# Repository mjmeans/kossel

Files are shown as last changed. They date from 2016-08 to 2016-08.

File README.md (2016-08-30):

Release status
==============

This is for my modified Kossel Mini using 15mm OpenBeam extrusions 360x750.

Credits
=======

* Based on Johann Rocholl's https://github.com/jcrocholl/kossel.
* recirculating.scad, recirculating.stl from https://github.com/jcrocholl/recirculating.
* framebrace_v2.stl from http://www.thingiverse.com/thing:626279.
* riser.scad, riser.stl from http://www.thingiverse.com/thing:705780.
* new_plate.stl, new_endstop.stl from http://www.thingiverse.com/thing:781634.
* TopMntBracket.stl from http://www.thingiverse.com/thing:843485.
* clip.scad, clip.stl from http://www.thingiverse.com/thing:783810
* molex_clips.stl, pscover_v2.scad, pscover_v2_with_aux_struts.stl from http://www.thingiverse.com/thing:235754.
* 3DR_LCD_Bracket_rev1.STL, 3DR_LCD_Pivot_rev1.STL from http://www.thingiverse.com/thing:467289.
* bracket_long.stl from http://www.thingiverse.com/thing:996476.
* ob-tube-jig_x6.stl from http://www.thingiverse.com/thing:291455.
* plate.stl, Bearing-flanged.stl from http://www.thingiverse.com/thing:454808.
* 3D_PlastX_reel_adapter.stl from http://www.thingiverse.com/thing:1666487.
* Kossel_Endstop_Mount.stl from http://www.thingiverse.com/thing:1305559.
* Kossel_Cable_Tidy.stl from http://www.thingiverse.com/thing:523867.
* mk_arm_clamp_short.stl from http://www.thingiverse.com/thing:330482.
* Dasaki_ramps_enclosure_base_kossel.stl from http://www.thingiverse.com/thing:1308919.
* dasaki_ramps_enclosure_cover_v2.stl from http://www.thingiverse.com/thing:761806.
* B-struder_1515_90_plate.stl from http://www.thingiverse.com/thing:1132070.
* B-struder_arm_M5.stl from http://www.thingiverse.com/thing:711401.
* 3DR_Pablo_LCD_distance_cylinder.stl, 3DR_Pablo_LCD_button_kill_improved.stl, 3DR_Pablo_LCD_case_bottom.stl, 3DR_Pablo_LCD_case_top.stl from http://www.thingiverse.com/thing:213852.
* zprobe_clamp.stl from http://www.thingiverse.com/thing:117981.
* Filament_Guide.stl from https://www.thingiverse.com/thing:1327363.

Things I modified
=================

* kossel-plus-fsr-holders-modified\* based on https://www.youmagine.com/designs/kossel-plus-fsr-holders. Modified by me to include a nut pocket.
* Kossel_Mini_Custom_Z_Probe_Retractable_-_3mm_probe_modified\ basd on http://www.thingiverse.com/thing:317205. Modified by me as follows: use an actual 3mm brass rod instead of 1/8"; lower it so that the arm bend in the rod sits at the effector level to allow for a longer arm; center the holder so that the rod sits direclty between the effector screws; strengthen the foot and add another small foot to go underneath the effector.

Things I made
=============

* spool_adapter_shim.* so that the longer arm designed to fit a 20mm extrusion will fit snug on 15mm extrusions.
* lcd_mount_bushing.* so that the 3DR_LCD_Bracket_rev1.STL designed for larger bolt will work with M3 bolt.
* kossel_retractable_helper.* so that the retractable z probe can be stowed directly at the back of the printer with a cool look like the frame braces.

Links
=====

* Bill of Materials: http://reprap.org/wiki/Kossel
* Mailing list: http://groups.google.com/group/deltabot
* Project history: http://deltabot.tumblr.com

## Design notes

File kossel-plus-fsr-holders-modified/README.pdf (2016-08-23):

# Kossel Plus FSR Holders

## By: (Haydn Huntley)

License: Commercial use is not allowed, you must attribute the creator, you may remix this work and the remixed work should be made available under

this license.

## Published on: Apr 01, 2016 Located at: http://www.youmagine.com/designs/kossel-plus-fsr-holders Short description:

These hold 3 FSR's, which the glass bed rests on, so that you can use the tip of the hotend as the probe. This system works extremely well! Description: <p>This FSR holder works quite well.</p><p>It is easy to modify it for different diameter or

thickness glass beds.</p><p>You can place small (approximately 1mm thick 5mm x 5mm) squares of foam between the glass and the key piece which swivels to lock the glass in place. &nbsp;This pre-loads the FSR so that you can better control how sensitive it is.</p><p>I used a drop of rubber cement to attach the round plastic buttons to the bottom of the glass. &nbsp;This keeps the glass

from being able to rotate.</p><p>The glass should lightly rest against the heads of the socket head cap screws so that it can easily move up and down. &nbsp;Tap on the glass to verify that the microcontroller triggers easily&nbsp;--&nbsp;a&nbsp;red&nbsp;LED&nbsp;will light&nbsp;when

it&nbsp;triggers.</p><p>The sensitive area is a triangle with the three FSR's at its corners.</p><p>I use Wing&nbsp;Wong &amp;&nbsp;Ian&nbsp;Lee's&nbsp;code for the Adafruit Trinket, but you could use this with John SL's board. &nbsp;With a Trinket, wire all three FSR's in parallel, so that pressing on any one will trigger it. &nbsp;Note:

the&nbsp;Trinket&nbsp;code&nbsp;is not&nbsp;limited&nbsp;by&nbsp;any&nbsp;license.</p><p>Someone&nbsp;else&nbsp;also&nbsp;made&nbsp;the&nbsp;Trinket&nbsp;wiring&nbsp;diagram.&nbsp;Note:&nbsp;I&nbsp;found&nbsp;I&nbsp;had&nbsp;to&nbsp;wire&nbsp;5v

from&nbsp;the&nbsp;RAMPS&nbsp;to&nbsp;USB+&nbsp;on the&nbsp;Trinket. &nbsp;The&nbsp;BAT+&nbsp;input&nbsp;is&nbsp;for&nbsp;more&nbsp;than&nbsp;5v&nbsp;(for&nbsp;example&nbsp;from

a&nbsp;battery),&nbsp;and&nbsp;the&nbsp;voltage&nbsp;regulator&nbsp;it
is&nbsp;attached&nbsp;to&nbsp;seems&nbsp;to&nbsp;require&nbsp;a&nbsp;little&nbsp;more&nbsp;than&nbsp;5v&nbsp;to deliver&nbsp;5v&nbsp;to&nbsp;operate&nbsp;the&nbsp;Trinket.<br></p><p>I have been building Kossel Plus printers (my own design) using these. &nbsp;They allow the effector to be

simpler, because it doesn't have to include a z-probe. &nbsp;I use RC's Marlin for auto calibration. &nbsp;Here is a link to&nbsp;my&nbsp;calibration&nbsp;instructions: &nbsp;<a rel="nofollow"

target="_blank" href="http://www.maui- 3d.com/kcZeroBacklashInstallation.php#calibration">http://www.maui- 3d.com/kcZeroBacklashInstallation.php#calibration</a></p>

If you can, please use the online documentation found at http://www.youmagine.com/designs/kossel- plus-fsr-holders because those may have been been updated. Also, there you can interact and

provide praise and/or feedback.

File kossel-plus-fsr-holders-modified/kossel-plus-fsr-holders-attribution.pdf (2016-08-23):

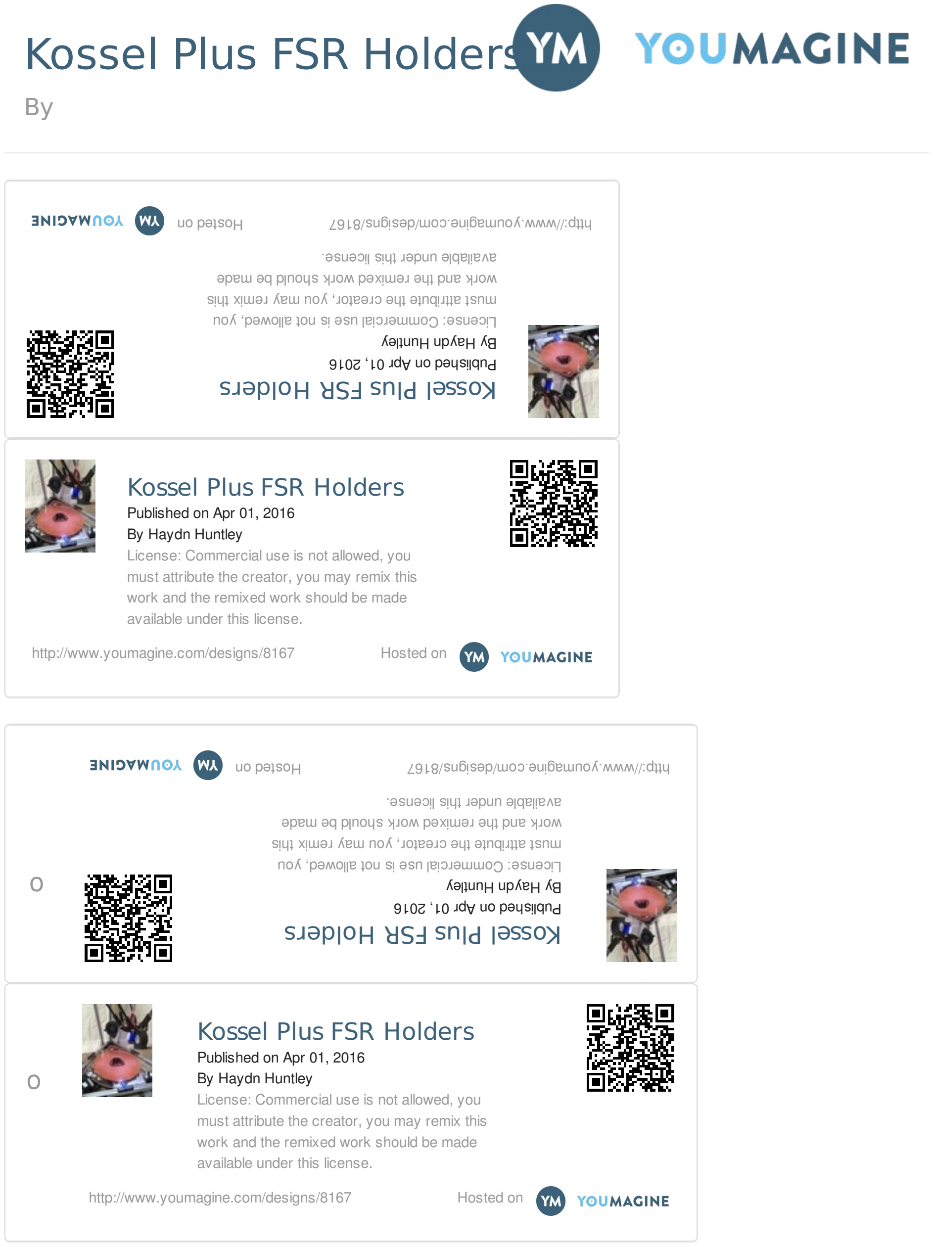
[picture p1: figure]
Kossel Plus FSR Holders; Published on Apr 01, 2016 By Haydn Huntley; available under this license.; http://www.youmagine.com/designs/8167; Hosted on

License: Commercial use is not allowed, you must attribute the creator, you may remix this work and the remixed work should be made

License: Commercial use is not allowed, you must attribute the creator, you may remix this work and the remixed work should be made

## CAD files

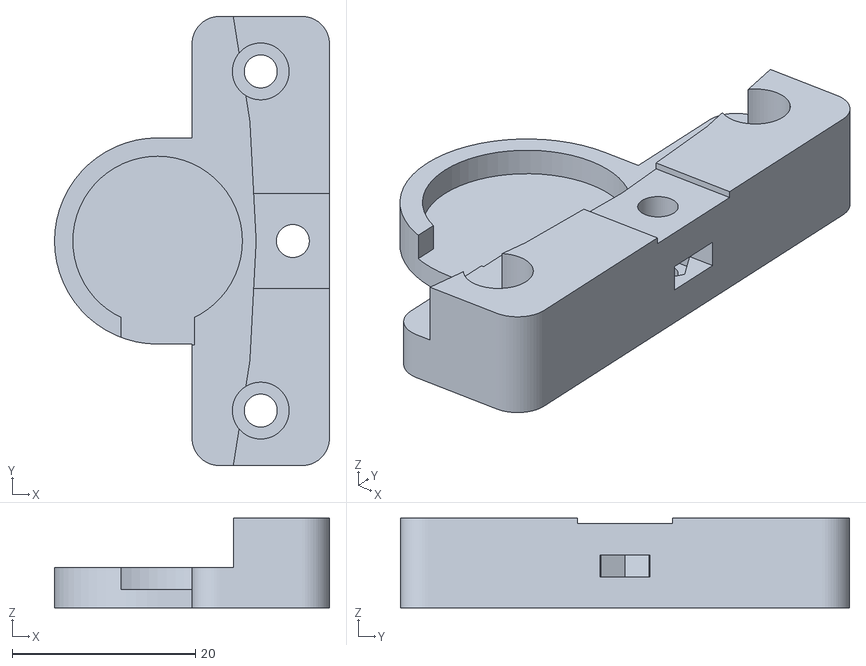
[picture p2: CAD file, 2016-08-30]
kossel-plus-fsr-holders-modified/fsrHolder.stl
30.0 x 49.0 x 9.80

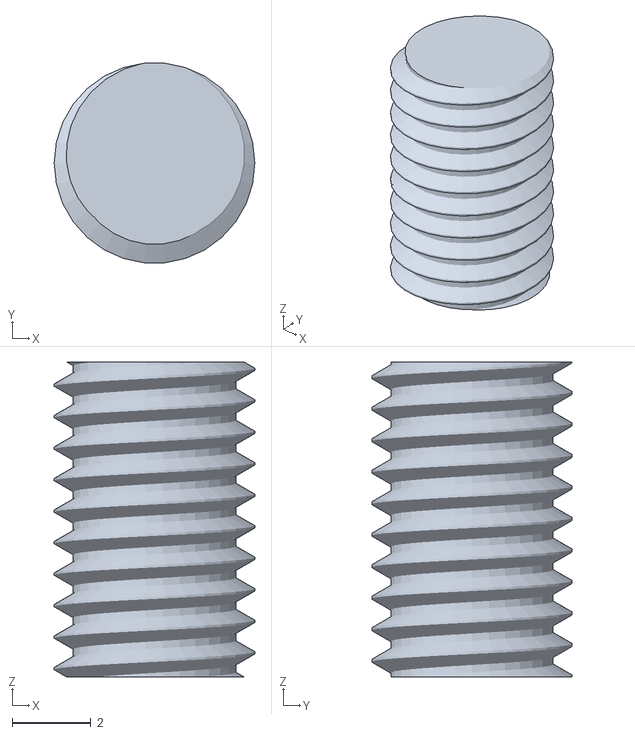
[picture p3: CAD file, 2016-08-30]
Kossel_Mini_Custom_Z_Probe_Retractable_-_3mm_probe_modified/m5_internal.stl
5.10 x 5.07 x 8.00

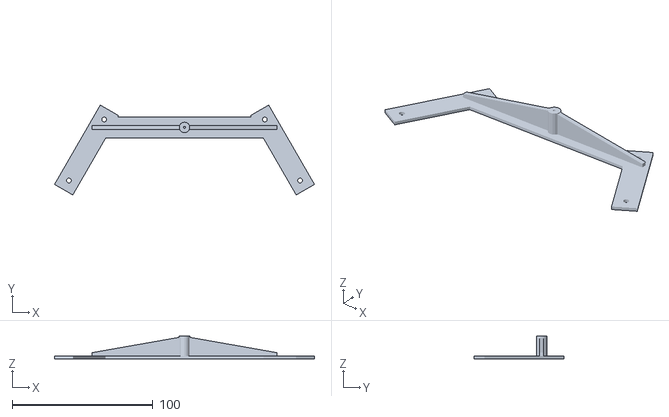
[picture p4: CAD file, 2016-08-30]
kossel_retractable_helper.stl
184.5 x 63.8 x 16.0

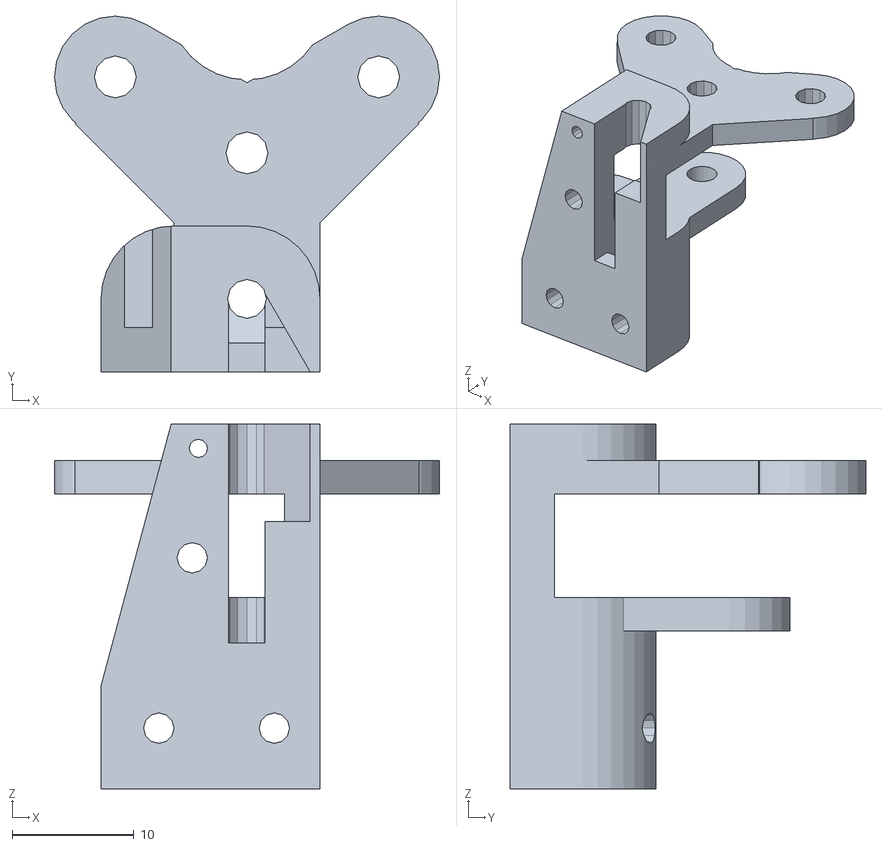
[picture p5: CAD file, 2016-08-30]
Kossel_Mini_Custom_Z_Probe_Retractable_-_3mm_probe_modified/retractable-custom.stl
31.7 x 29.2 x 30.0

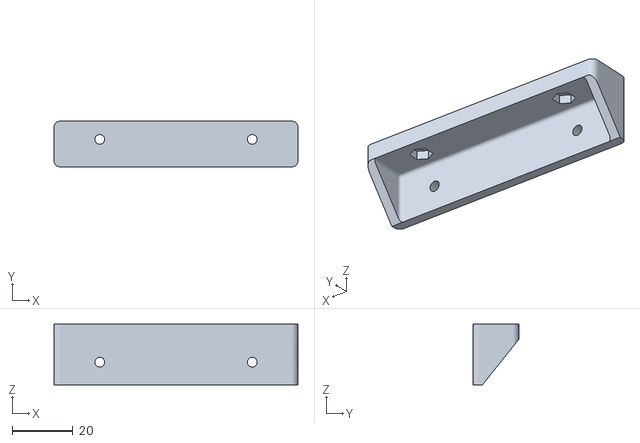
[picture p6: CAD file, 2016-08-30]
TopMntBracket.stl
80.0 x 15.0 x 20.0

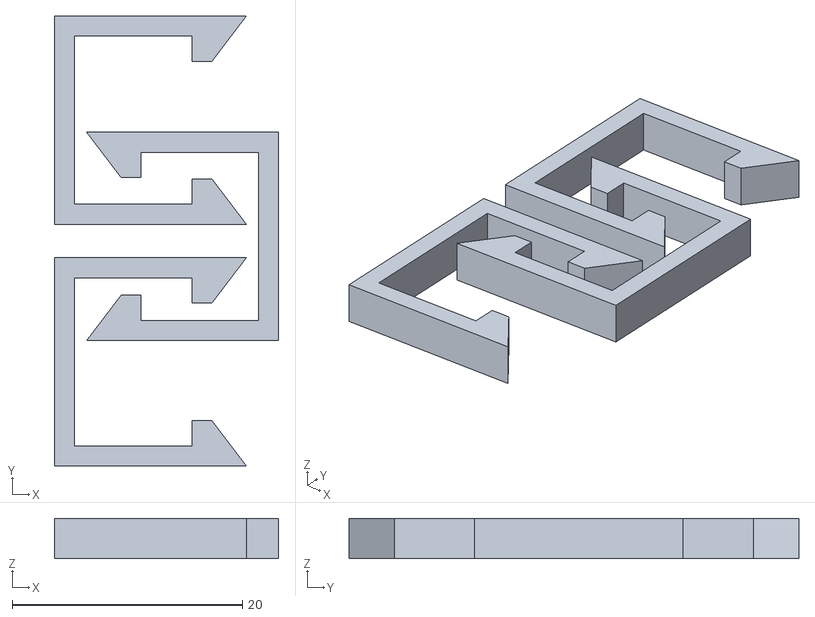
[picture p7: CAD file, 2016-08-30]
molex_clips.stl
19.5 x 39.1 x 3.50

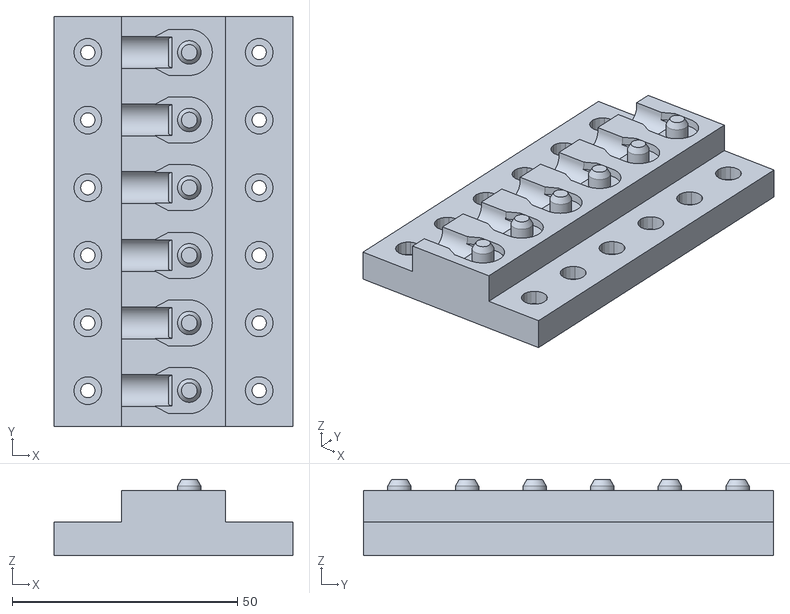
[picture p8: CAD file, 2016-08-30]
ob-tube-jig_x6.stl
53.0 x 91.0 x 16.9

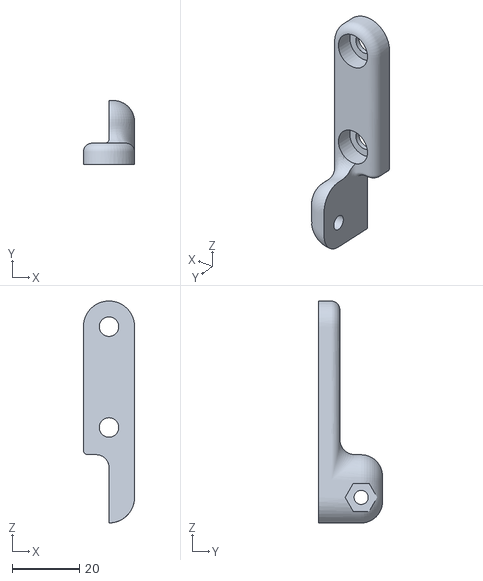
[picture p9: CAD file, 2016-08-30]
3DR_LCD_Bracket_rev1.STL
15.2 x 19.1 x 66.0

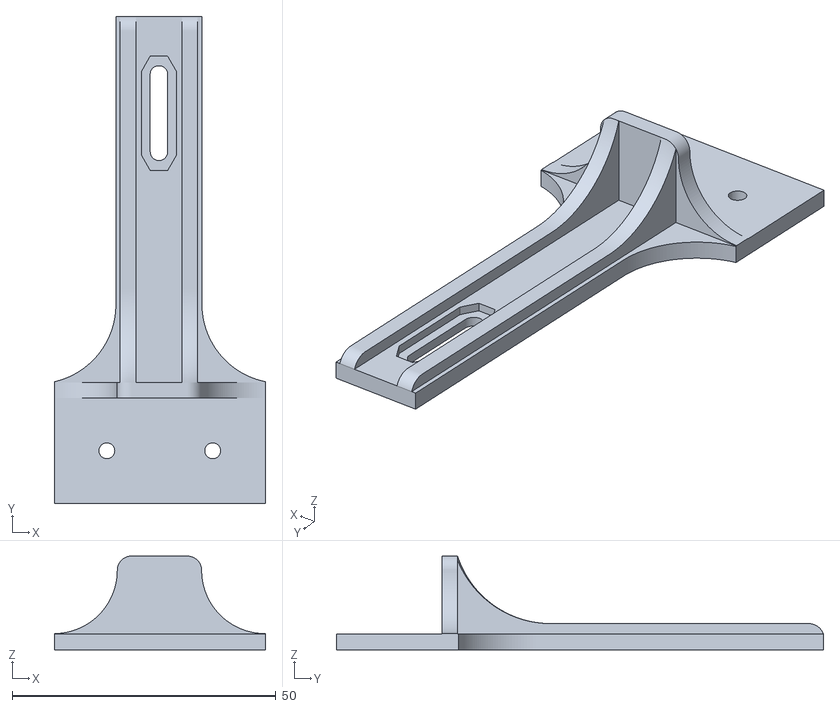
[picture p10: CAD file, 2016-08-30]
bracket_long.stl
40.0 x 92.3 x 17.8

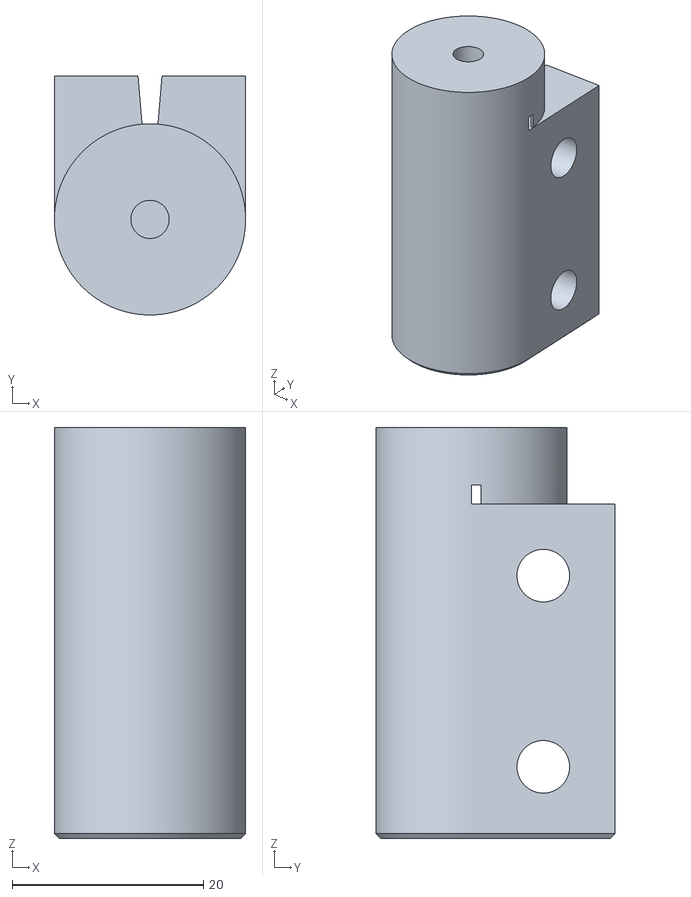
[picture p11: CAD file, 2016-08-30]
mk_arm_clamp_short.stl
20.0 x 25.0 x 43.0

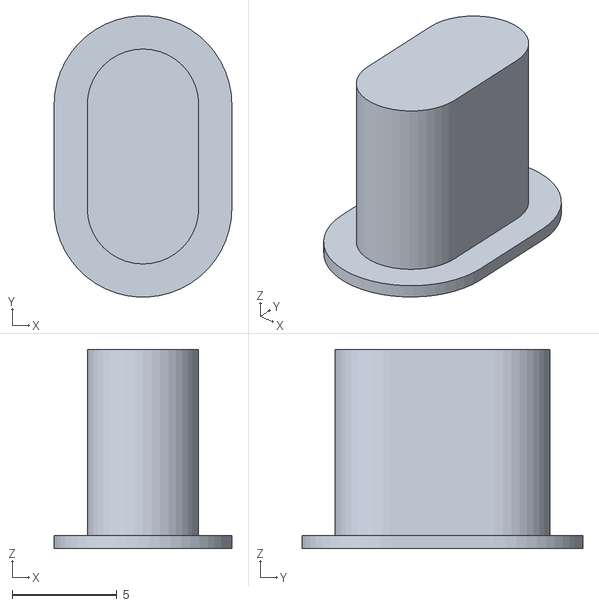
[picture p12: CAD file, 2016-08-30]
3DR_Pablo_LCD_button_kill_improved.stl
8.51 x 13.4 x 9.53

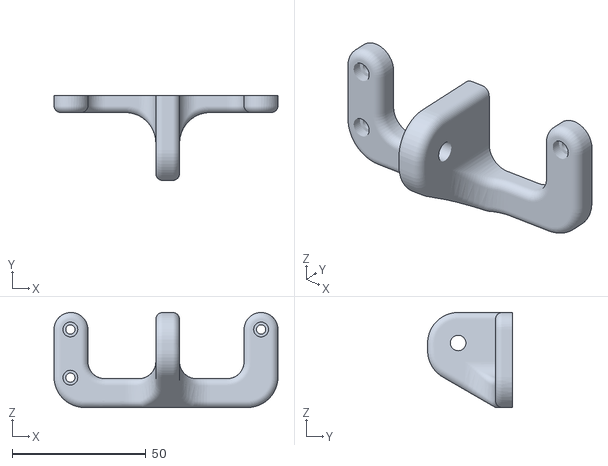
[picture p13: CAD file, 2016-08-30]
3DR_LCD_Pivot_rev1.STL
83.8 x 31.8 x 35.6

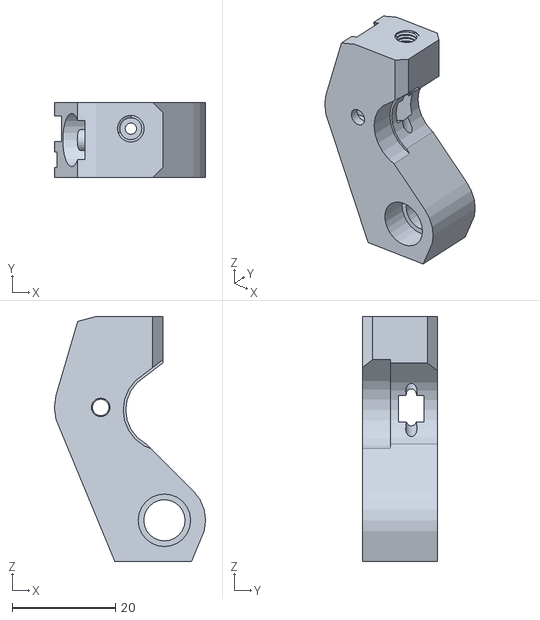
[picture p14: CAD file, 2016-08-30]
B-struder_arm_M5.stl
29.4 x 14.6 x 47.6

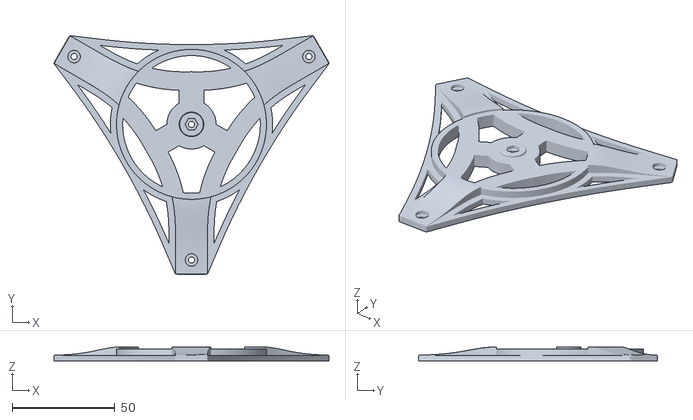
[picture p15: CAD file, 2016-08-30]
plate.stl
133.9 x 116.2 x 7.00

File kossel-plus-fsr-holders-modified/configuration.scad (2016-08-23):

smidge              =  0.1;
mmPerInch			= 25.4;
m3Radius            = (3.0 + 0.2) / 2;
m3LooseRadius		= m3Radius + 0.2;
m3HeadHeight        = 3.0;
m3LooseHeadRadius   = (5.4 + 0.6) / 2;
m3NutRadius         = 6.01 / 2;
m3NutRadiusMin      = 5.5 / 2;
m3LooseNutRadius    = m3NutRadius + 0.2;
m3NutHeight			= 2.4;
m3LockNutRadius     = (6.25 + 0.75) / 2;
m3LockNutHeight     = 4.0;
ballJointSeparation = 48.0;
ballRadius			= (3/8 * mmPerInch)/2;
ballBaseRadius		= 10.0 / 2;
extrusionWidth		= 15.0;
glassRadius			= 125.0;
glassHeight			= 3.4;
nozzleWidth			= 0.5;

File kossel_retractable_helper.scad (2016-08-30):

//118
mount_length=50.0;    // the length of the mount sides
mount_width=15.0;     // the width of the mount sides
mount_thickness=2.0;  // the thickness of the mount sides
span_width=139;
span_y_offset=16;   // 22
riser_height=15;
riser_thickness=3;
$fn=16;

// Increase this if your slicer or printer make holes too tight.
extra_radius = 0.1;

// Major diameter of metric 3mm thread.
m3_major = 2.85;
m3_radius = m3_major/2 + extra_radius;
m3_wide_radius = m3_major/2 + extra_radius + 0.2;

difference() {
    union() {
        // mounting bars
        translate([span_width/2,0,0]) rotate([0,0,30]) bar();
        translate([-span_width/2,0,0]) rotate([0,0,-30]) bar();
        // span between bars
        translate([0,span_y_offset,0]) union() {
            translate([0,mount_width/4,0])
                cube([span_width-span_y_offset*2,mount_width/2,mount_thickness], center=true);
            translate([0,-mount_width/4,0])
                cube([span_width-span_y_offset,mount_width/2,mount_thickness], center=true);
        }
        translate([0,span_y_offset,0])
            cylinder(r=mount_width/4, h=riser_height);
        difference() {
            translate([0,span_y_offset,riser_height/2])
                cube([span_width-span_y_offset/2,riser_thickness,riser_height], center=true);
            translate([0,span_y_offset,riser_height+riser_height/2]) rotate([0,10,0]) 
                cube([span_width*2-span_y_offset,riser_thickness,riser_height], center=true);
            translate([0,span_y_offset,riser_height+riser_height/2]) rotate([0,-10,0]) 
                cube([span_width*2-span_y_offset,riser_thickness,riser_height], center=true);
        }
    }
    translate([0,span_y_offset,0])
        cylinder(r=m3_radius/2, h=riser_height);
}

module bar() {
    difference() {
        cube([mount_width,mount_length+mount_width,mount_thickness], center=true);
        translate([0,mount_length/2,0]) cylinder(r=m3_wide_radius, h=mount_thickness, center=true);
        translate([0,-mount_length/2,0]) cylinder(r=m3_wide_radius, h=mount_thickness, center=true);
    }
}

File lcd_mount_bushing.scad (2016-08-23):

difference() {
    union() {
        cylinder(r=4.50, h=5, $fn=32);
        cylinder(r=2.75, h=6.5, $fn=32);
    }
    cylinder(r=1.75, h=7, $fn=32);
    cylinder(r=3.25, h=2.75, $fn=32);
    translate([0,0,2.75])
        cylinder(r1=3.25, r2=1.75, h=0.5, $fn=32);
    //cube([10,10,10]);
}

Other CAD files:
Dasaki_ramps_enclosure_base_kossel.stl
dasaki_ramps_enclosure_cover_v2.stl
pscover_v2_with_aux_structs.stl
3DR_Pablo_LCD_distance_cylinder.stl
spool_adapter_shim.scad
3DR_Pablo_LCD_case_bottom.stl
3DR_Pablo_LCD_case_top.stl
3D_PlastX_reel_adapter.stl
B-struder_1515_90_plate.stl
Bearing-flanged.stl
Filament_Guide.stl
Kossel_Cable_Tidy.stl
Kossel_Endstop_Mount.stl
Kossel_Mini_Custom_Z_Probe_Retractable_-_3mm_probe_modified/configuration.scad
Kossel_Mini_Custom_Z_Probe_Retractable_-_3mm_probe_modified/effector.scad
Kossel_Mini_Custom_Z_Probe_Retractable_-_3mm_probe_modified/hotend_fan.scad
Kossel_Mini_Custom_Z_Probe_Retractable_-_3mm_probe_modified/m5_internal.scad
Kossel_Mini_Custom_Z_Probe_Retractable_-_3mm_probe_modified/microswitch.scad
Kossel_Mini_Custom_Z_Probe_Retractable_-_3mm_probe_modified/retractable-custom.scad
clip.stl
framebrace_v2.stl
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

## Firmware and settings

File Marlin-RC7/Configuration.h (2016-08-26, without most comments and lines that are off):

#define CONFIGURATION_H
#define CONFIGURATION_H_VERSION 010100
#define STRING_CONFIG_H_AUTHOR "(none, default config)" // Who made the changes.
#define SHOW_BOOTSCREEN
#define STRING_SPLASH_LINE1 SHORT_BUILD_VERSION // will be shown during boot in line 1
#define STRING_SPLASH_LINE2 WEBSITE_URL         // will be shown during boot in line 2
#define SERIAL_PORT 0
#define BAUDRATE 250000
  #define MOTHERBOARD BOARD_RAMPS_14_EFB
#define CUSTOM_MACHINE_NAME "Mini Kossel 360/750"
#define EXTRUDERS 1
#define POWER_SUPPLY 1
#define TEMP_SENSOR_0 11  // UCTRONICS E3D V6 uses NTC 3950 pre-wired thermistor
#define TEMP_SENSOR_1 0
#define TEMP_SENSOR_2 0
#define TEMP_SENSOR_3 0
#define TEMP_SENSOR_BED 11
#define MAX_REDUNDANT_TEMP_SENSOR_DIFF 5
#define TEMP_RESIDENCY_TIME 10  // (seconds)
#define TEMP_HYSTERESIS 3       // (degC) range of +/- temperatures considered "close" to the target one
#define TEMP_WINDOW     1       // (degC) Window around target to start the residency timer x degC early.
#define TEMP_BED_RESIDENCY_TIME 0   // (seconds)
#define TEMP_BED_HYSTERESIS 3       // (degC) range of +/- temperatures considered "close" to the target one
#define TEMP_BED_WINDOW     1       // (degC) Window around target to start the residency timer x degC early.
#define HEATER_0_MINTEMP 5
#define HEATER_1_MINTEMP 5
#define HEATER_2_MINTEMP 5
#define HEATER_3_MINTEMP 5
#define BED_MINTEMP 5
#define HEATER_0_MAXTEMP 275
#define HEATER_1_MAXTEMP 275
#define HEATER_2_MAXTEMP 275
#define HEATER_3_MAXTEMP 275
#define BED_MAXTEMP 150
#define PIDTEMP
#define BANG_MAX 255 // limits current to nozzle while in bang-bang mode; 255=full current
#define PID_MAX BANG_MAX // limits current to nozzle while PID is active (see PID_FUNCTIONAL_RANGE below); 255=full current
  #define PID_FUNCTIONAL_RANGE 10 // If the temperature difference between the target temperature and the actual temperature
  #define PID_INTEGRAL_DRIVE_MAX PID_MAX  //limit for the integral term
  #define K1 0.95 //smoothing factor within the PID
  #define  DEFAULT_Kp 24.31
  #define  DEFAULT_Ki 1.92
  #define  DEFAULT_Kd 77.06
#define PIDTEMPBED
#define MAX_BED_POWER 255 // limits duty cycle to bed; 255=full current
  #define PID_BED_INTEGRAL_DRIVE_MAX MAX_BED_POWER //limit for the integral term
  #define  DEFAULT_bedKp 217.87
  #define  DEFAULT_bedKi 12.59
  #define  DEFAULT_bedKd 942.38
#define PREVENT_DANGEROUS_EXTRUDE
#define PREVENT_LENGTHY_EXTRUDE
#define EXTRUDE_MINTEMP 170
#define EXTRUDE_MAXLENGTH (X_MAX_LENGTH+Y_MAX_LENGTH) //prevent extrusion of very large distances.
#define THERMAL_PROTECTION_HOTENDS // Enable thermal protection for all extruders
#define THERMAL_PROTECTION_BED     // Enable thermal protection for the heated bed
#define DELTA
  #define DELTA_SEGMENTS_PER_SECOND 200
  #define DELTA_DIAGONAL_ROD 288.0 // mm (kossel_frame_calc.xls says it should be 350.5, mk_visual_calc says it should be 296.887)
  #define DELTA_SMOOTH_ROD_OFFSET 221.12505 // mm
  #define DELTA_EFFECTOR_OFFSET 20.0 // mm (kossel_frame_calc.xls says it should be 20.0)
  #define DELTA_CARRIAGE_OFFSET 27.4 // mm (kossel_frame_calc.xls says it should be 27.0)
  #define DELTA_RADIUS (DELTA_SMOOTH_ROD_OFFSET-(DELTA_EFFECTOR_OFFSET)-(DELTA_CARRIAGE_OFFSET))
  #define DELTA_PRINTABLE_RADIUS 135.0
#define USE_ZMIN_PLUG
#define USE_XMAX_PLUG
#define USE_YMAX_PLUG
#define USE_ZMAX_PLUG
#define ENDSTOPPULLUPS // Comment this out (using // at the start of the line) to disable the endstop pullup resistors
#define X_MIN_ENDSTOP_INVERTING false // set to true to invert the logic of the endstop.
#define Y_MIN_ENDSTOP_INVERTING false // set to true to invert the logic of the endstop.
#define Z_MIN_ENDSTOP_INVERTING false // set to true to invert the logic of the endstop.
#define X_MAX_ENDSTOP_INVERTING false // set to true to invert the logic of the endstop.
#define Y_MAX_ENDSTOP_INVERTING false // set to true to invert the logic of the endstop.
#define Z_MAX_ENDSTOP_INVERTING false // set to true to invert the logic of the endstop.
#define Z_MIN_PROBE_ENDSTOP_INVERTING false // set to true to invert the logic of the endstop.
#define X_PROBE_OFFSET_FROM_EXTRUDER 0     // X offset: -left  +right  [of the nozzle]
#define Y_PROBE_OFFSET_FROM_EXTRUDER 20   // Y offset: -front +behind [the nozzle]
#define Z_PROBE_OFFSET_FROM_EXTRUDER -3  // Z offset: -below +above  [the nozzle]
#define XY_PROBE_SPEED 4000
#define Z_PROBE_SPEED_FAST HOMING_FEEDRATE_Z
#define Z_PROBE_SPEED_SLOW (Z_PROBE_SPEED_FAST / 2)
#define Z_PROBE_ALLEN_KEY
  #define Z_PROBE_ALLEN_KEY_DEPLOY_1_X 30.0
  #define Z_PROBE_ALLEN_KEY_DEPLOY_1_Y DELTA_PRINTABLE_RADIUS
  #define Z_PROBE_ALLEN_KEY_DEPLOY_1_Z 135.0
  #define Z_PROBE_ALLEN_KEY_DEPLOY_1_FEEDRATE XY_PROBE_SPEED
  #define Z_PROBE_ALLEN_KEY_DEPLOY_2_X 5.0
  #define Z_PROBE_ALLEN_KEY_DEPLOY_2_Y DELTA_PRINTABLE_RADIUS
  #define Z_PROBE_ALLEN_KEY_DEPLOY_2_Z 135.0
  #define Z_PROBE_ALLEN_KEY_DEPLOY_2_FEEDRATE (XY_PROBE_SPEED/10)
  #define Z_PROBE_ALLEN_KEY_DEPLOY_3_X Z_PROBE_ALLEN_KEY_DEPLOY_2_X * 0.75
  #define Z_PROBE_ALLEN_KEY_DEPLOY_3_Y Z_PROBE_ALLEN_KEY_DEPLOY_2_Y * 0.75
  #define Z_PROBE_ALLEN_KEY_DEPLOY_3_Z Z_PROBE_ALLEN_KEY_DEPLOY_2_Z
  #define Z_PROBE_ALLEN_KEY_DEPLOY_3_FEEDRATE XY_PROBE_SPEED
  #define Z_PROBE_ALLEN_KEY_STOW_DEPTH 20
  #define Z_PROBE_ALLEN_KEY_STOW_1_X 0.0
  #define Z_PROBE_ALLEN_KEY_STOW_1_Y 117.0
  #define Z_PROBE_ALLEN_KEY_STOW_1_Z 23.0
  #define Z_PROBE_ALLEN_KEY_STOW_1_FEEDRATE XY_PROBE_SPEED
  #define Z_PROBE_ALLEN_KEY_STOW_2_X  Z_PROBE_ALLEN_KEY_STOW_1_X
  #define Z_PROBE_ALLEN_KEY_STOW_2_Y  Z_PROBE_ALLEN_KEY_STOW_1_Y
  #define Z_PROBE_ALLEN_KEY_STOW_2_Z  (Z_PROBE_ALLEN_KEY_STOW_1_Z-Z_PROBE_ALLEN_KEY_STOW_DEPTH)
  #define Z_PROBE_ALLEN_KEY_STOW_2_FEEDRATE (XY_PROBE_SPEED/10)
  #define Z_PROBE_ALLEN_KEY_STOW_3_X  Z_PROBE_ALLEN_KEY_STOW_2_X
  #define Z_PROBE_ALLEN_KEY_STOW_3_Y  Z_PROBE_ALLEN_KEY_STOW_2_Y
  #define Z_PROBE_ALLEN_KEY_STOW_3_Z  (Z_PROBE_ALLEN_KEY_STOW_1_Z+Z_PROBE_ALLEN_KEY_STOW_DEPTH)
  #define Z_PROBE_ALLEN_KEY_STOW_3_FEEDRATE (XY_PROBE_SPEED/2)
  #define Z_PROBE_ALLEN_KEY_STOW_4_X 0.0
  #define Z_PROBE_ALLEN_KEY_STOW_4_Y 0.0
  #define Z_PROBE_ALLEN_KEY_STOW_4_Z Z_PROBE_ALLEN_KEY_STOW_3_Z
  #define Z_PROBE_ALLEN_KEY_STOW_4_FEEDRATE XY_PROBE_SPEED
#define Z_MIN_PROBE_USES_Z_MIN_ENDSTOP_PIN
#define Z_PROBE_DEPLOY_HEIGHT 50 // Raise to make room for the probe to deploy / stow
#define Z_PROBE_TRAVEL_HEIGHT 8  // Raise between probing points.
#define Z_PROBE_OFFSET_RANGE_MIN -20
#define Z_PROBE_OFFSET_RANGE_MAX 20
#define X_ENABLE_ON 0
#define Y_ENABLE_ON 0
#define Z_ENABLE_ON 0
#define E_ENABLE_ON 0 // For all extruders
#define DISABLE_X false
#define DISABLE_Y false
#define DISABLE_Z false
#define DISABLE_E false // For all extruders
#define DISABLE_INACTIVE_EXTRUDER true //disable only inactive extruders and keep active extruder enabled
#define INVERT_X_DIR false // DELTA does not invert
#define INVERT_Y_DIR false
#define INVERT_Z_DIR false
#define INVERT_E0_DIR false
#define INVERT_E1_DIR false
#define INVERT_E2_DIR false
#define INVERT_E3_DIR false
#define X_HOME_DIR 1  // deltas always home to max
#define Y_HOME_DIR 1
#define Z_HOME_DIR 1
#define min_software_endstops true // If true, axis won't move to coordinates less than HOME_POS.
#define max_software_endstops true  // If true, axis won't move to coordinates greater than the defined lengths below.
#define X_MIN_POS -(DELTA_PRINTABLE_RADIUS)
#define Y_MIN_POS -(DELTA_PRINTABLE_RADIUS)
#define Z_MIN_POS 0
#define X_MAX_POS DELTA_PRINTABLE_RADIUS
#define Y_MAX_POS DELTA_PRINTABLE_RADIUS
#define Z_MAX_POS MANUAL_Z_HOME_POS
#define AUTO_BED_LEVELING_FEATURE // Delete the comment to enable (remove // at the start of the line)
  #define AUTO_BED_LEVELING_GRID  // Deltas only support grid mode.
    #define DELTA_PROBEABLE_RADIUS (DELTA_PRINTABLE_RADIUS - 40)
    #define LEFT_PROBE_BED_POSITION -(DELTA_PROBEABLE_RADIUS)
    #define RIGHT_PROBE_BED_POSITION DELTA_PROBEABLE_RADIUS
    #define FRONT_PROBE_BED_POSITION -(DELTA_PROBEABLE_RADIUS)
    #define BACK_PROBE_BED_POSITION DELTA_PROBEABLE_RADIUS
    #define MIN_PROBE_EDGE 10 // The Z probe minimum square sides can be no smaller than this.
    #define AUTO_BED_LEVELING_GRID_POINTS 9
#define BED_CENTER_AT_0_0
#define MANUAL_Z_HOME_POS 255 // Distance between the nozzle to printbed after homing
#define HOMING_FEEDRATE_Z  (200*60)
#define XYZ_FULL_STEPS_PER_ROTATION 200
#define XYZ_MICROSTEPS 16
#define XYZ_BELT_PITCH 2
#define XYZ_PULLEY_TEETH 20
#define XYZ_STEPS (XYZ_FULL_STEPS_PER_ROTATION * XYZ_MICROSTEPS / double(XYZ_BELT_PITCH) / double(XYZ_PULLEY_TEETH))
#define E_FULL_STEPS_PER_ROTATION 200
#define E_MICROSTEPS 16
#define E_HOB_DIAM 7.1    // http://reprap.org/wiki/Drive-gear (TriDPrinting MK8)
#define E_BIG_GEAR_TEETH 1
#define E_SMALL_GEAR_TEETH 1
#define E_STEPS ((E_FULL_STEPS_PER_ROTATION * E_MICROSTEPS) * (E_BIG_GEAR_TEETH / double(E_SMALL_GEAR_TEETH)) / (double(E_HOB_DIAM) * double(3.14159265)))
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

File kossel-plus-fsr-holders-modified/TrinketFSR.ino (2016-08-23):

/*
  Modified version of JohnSL's FSR Trigger for use on the Trinket or ATtiny85
  From: https://github.com/ianlee74/AutoTuningFSRTrigger/blob/master/JohnSL_Trigger_Rewritten_For_Trinket_usingInternalPullUps/JohnSL_Trigger_Rewritten_For_Trinket_usingInte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
  And from: http://trains.socha.com/2014/07/updating-fsr-endstop-controller-firmware.html

  Loses the following features from his design:
  * Loses LED indicators per FSR
  * Loses Various other IO pins
  
  Retains the following:
  * 1 FSR input (wire the three FSR's in parallel to pin #2)
  * JohnSL's long and short averaging routines
  
  Changes:
  * Changed the LED and endstop/output pin to pins #1 and #0.
  * Changed the ADC chosen to be A1, A2, and A3. (A0 is the reset pin on the
     ATtiny85)

  Changes by Haydn Huntley (haydn.huntley@gmail.com):
  * Ported one of JohnSL's recent improvements, which lowers the response time
     to within ~5ms.
*/
  
// Define the pin that has an LED on it. We have an LED for the FSR to indicate
// when the FSR is triggered. And one power/end stop LED that is on until an
// FSR is triggered.
#define LEDTRIGGER  01
// The end stop output
#define ENDSTOP     00

short fsrPin = 2;               // The pin for the FSR analog input
short fsrAnalogNum = 1;         // Analog pin number to use with analogRead()

#define SHORT_SIZE 8
#define LONG_SIZE 16
#define LONG_INTERVAL (2000 / LONG_SIZE)

unsigned long lastLongTime;              // Last time in millis that we captured a long-term sample
uint16_t longSamples[LONG_SIZE];         // Used to keep a long-term average
uint8_t longIndex = 0;                   // Index of the last long-term sample
uint16_t longAverage = 0;

uint16_t shortSamples[SHORT_SIZE];       // Used to create an average of the most recent samples
uint8_t averageIndex = 0;

void SetOutput(bool triggered)
{
	// Turns on the FSR LED when the FSR is triggered.
    digitalWrite(LEDTRIGGER, triggered);
    // Send the signal for the Z-probe.
    digitalWrite(ENDSTOP, triggered);
}

void InitValues()
{
  for (uint8_t i = 0; i < SHORT_SIZE; i++)
    shortSamples[i] = 0;

  for (uint8_t i = 0; i < LONG_SIZE; i++)
    longSamples[i] = 0;

  lastLongTime = millis();
}

//
// One-time setup for the various I/O ports
//
void setup()
{
  InitValues();

  pinMode(fsrPin, INPUT);
  digitalWrite(fsrPin, HIGH);  // Use the internal pull-up resistors.

  // Set the green combined LED to on so it acts as a power-on indicator.
  // We'll turn it off whenever we trigger the end stop.
  pinMode(LEDTRIGGER, OUTPUT);
  digitalWrite(LEDTRIGGER, HIGH);

  // Set the endstop pin to be an output that is set for NC
  pinMode(ENDSTOP, OUTPUT);
  digitalWrite(ENDSTOP, LOW);
};

//
// Captures a new value once LONG_INTERVAL ms have passed since the last sample.
//
// Returns: The current long-range average
uint16_t UpdateLongSamples(int avg)
{
  // If enough time hasn't passed, just return the last value.
  unsigned long current = millis();
  if (current - lastLongTime <= LONG_INTERVAL)
    return longAverage;

  // Update the long sample with the new value, and then update the long average.
  longSamples[longIndex++] = avg;
  if (longIndex >= LONG_SIZE)
      longIndex = 0;

  uint16_t total = 0;
  for (int i = 0; i < LONG_SIZE; i++)
    total += longSamples[i];
    
  longAverage = total / LONG_SIZE;

  lastLongTime = millis();
  return longAverage;
}

void CheckIfTriggered()
{
  // Calculate the average of the most recent short-term samples.
  uint16_t total = 0;
  for (int i = 0; i < SHORT_SIZE; i++)
  {
    total += shortSamples[i];
  }
  uint16_t avg = total / SHORT_SIZE;
  uint16_t longAverage = UpdateLongSamples(avg);
  uint16_t threshold = 0.85 * longAverage;
  bool triggered = avg < threshold;
  SetOutput(triggered);
}

void loop()
{
  int value = analogRead(fsrAnalogNum);
  shortSamples[averageIndex++] = value;
  if (averageIndex >= SHORT_SIZE)
    averageIndex = 0;
  CheckIfTriggered();
};

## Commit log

2016-08-23 My Kossel
    [carriage.scad, carriage.stl, configuration.scad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]
2016-08-26 Marlin RC7 files
    Use Marlin RC7, then replace these files.
    [Configuration.h]
2016-08-30 All the STL's
    [3DR_LCD_Bracket_rev1.STL, 3DR_LCD_Pivot_rev1.STL, 3DR_Pablo_LCD_button_kill_improved.stl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]

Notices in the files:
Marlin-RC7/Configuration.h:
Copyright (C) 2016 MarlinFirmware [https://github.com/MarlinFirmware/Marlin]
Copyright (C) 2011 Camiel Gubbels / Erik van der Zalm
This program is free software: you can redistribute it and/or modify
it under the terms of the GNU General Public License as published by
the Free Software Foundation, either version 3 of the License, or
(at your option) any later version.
